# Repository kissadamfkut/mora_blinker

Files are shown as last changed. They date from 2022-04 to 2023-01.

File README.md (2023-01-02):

Mora-blinker
========== 
## Goals
  
- Provide a simple and cheap educational embedded project
- Demonstrate basic electric design 
- Demonstrate both C++ basics and advanced tricks
- More entertaining first program than a 'Hello world'
- Educate for software design in low-end environments

## How to use

- The schematics and the PCB board can be found in the hw folder. You can open the files with KiCAD 6
- The software is in the sw folder. Do not forget to also pull the git submodules!
- The build environment for the software includes avr-gcc 11.2, avrdude 6.4 and make 4.3
- Do not connect the battery when using a 5V ISP!
- After building the PCB, connect an STK500 or similar, and type ```make program```
- You can switch animations with the reset button

## Bill of materials

- CR2032 holder
- CR2032
- 100 nF capacitor
- Yellow LEDs (x5)
- 120 ohm resistors (x5)
- 9.1 kohm resistor
- Button
- ATtiny13A

## Theory of operation

The timer overflow interrupt drives a soft-PWM routine. The running animation changes an array of the LEDs' duty cycles. Resetting the device, the content of the SRAM is not random, so the index of the last animation is known, except for the cold-start, when it is random (not a problem). Some data is stored in the EEPROM to save space.
   
## Known issues  
  
- Fuse calculation could be more describing
- May further optimize base code
- Less numeric constant

## Work of a student

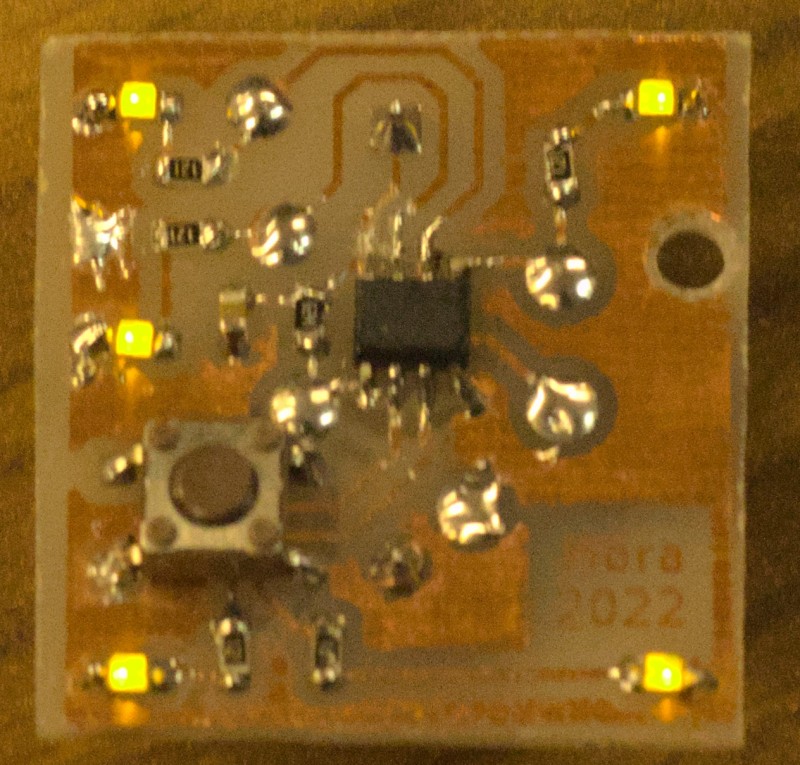
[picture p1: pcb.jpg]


## Full installion on Debian systems
```bash
sudo apt intsall gcc-avr avr-libc make avrdude
cd sw
make
make program
sudo apt install kdevelop #Optional
```

## Full installation on Windows systems (not tested)
- Install the lates AVR-GCC (for eg. https://blog.zakkemble.net/avr-gcc-builds/)
- Install Code::Blocks (https://www.codeblocks.org/)
- Open the project, and compile the elf file
- Use the driver of the programmer to deploy the code

## FAQ
Sometimes the programmers' device files are created with special permission on linux based systems. You should gather unix group membership to the proper group (dialout, uucp etc.), so you can program your device without sudo

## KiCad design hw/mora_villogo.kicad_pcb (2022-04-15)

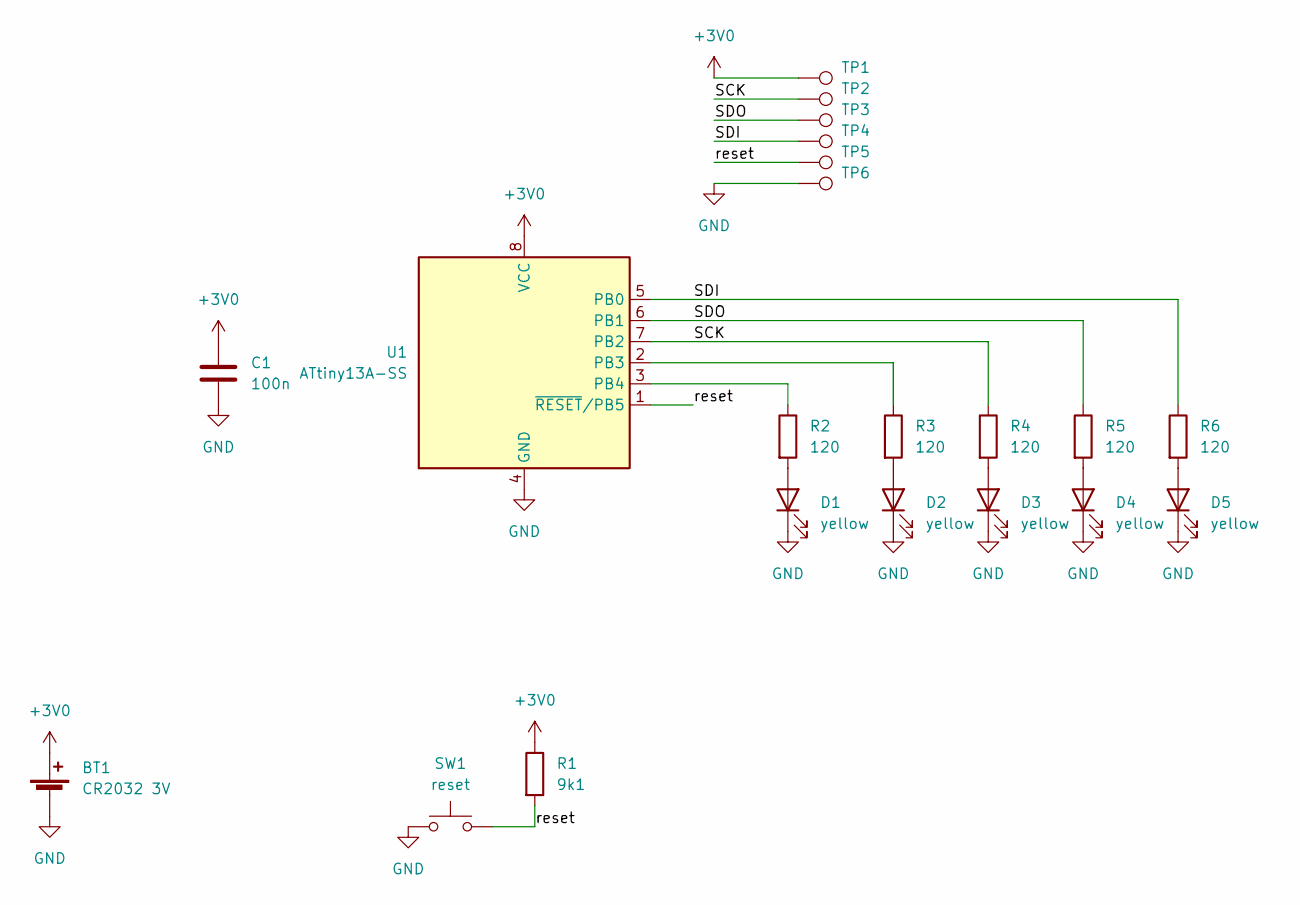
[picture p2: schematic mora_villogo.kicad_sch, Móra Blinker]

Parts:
BT1: CR2032 3V; BatteryHolder_ComfortableElectronic_CH273-2450_1x2450
C1: 100n; C_0805_2012Metric_Pad1.18x1.45mm_HandSolder
D1, D2, D3, D4, D5: yellow; LED_0805_2012Metric_Pad1.15x1.40mm_HandSolder
R1: 9k1; R_0805_2012Metric_Pad1.20x1.40mm_HandSolder
R2, R3, R4, R5, R6: 120; R_0805_2012Metric_Pad1.20x1.40mm_HandSolder
SW1: reset; SW_Push_1P1T_NO_6x6mm_H9.5mm
TP1, TP2, TP3, TP4, TP5, TP6: TestPoint; TestPoint_Pad_D3.0mm
U1: ATtiny13A-SS; SOIC-8_3.9x4.9mm_P1.27mm

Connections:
+3V0: BT1.1 (+), C1.1, R1.1, TP1.1, U1.8 (VCC)
/SCK: R4.1, TP2.1, U1.7 (PB2)
/SDI: R6.1, TP4.1, U1.5 (PB0)
/SDO: R5.1, TP3.1, U1.6 (PB1)
/reset: R1.2, SW1.2, TP5.1, U1.1 (~RESET/PB5)
GND: BT1.2 (-), C1.2, D1.1 (K), D2.1 (K), D3.1 (K), D4.1 (K), D5.1 (K), SW1.1, TP6.1, U1.4 (GND)
unnamed: D1.2 (A), R2.2
unnamed: D2.2 (A), R3.2
unnamed: D3.2 (A), R4.2
unnamed: D4.2 (A), R5.2
unnamed: D5.2 (A), R6.2
unnamed: R2.1, U1.3 (PB4)
unnamed: R3.1, U1.2 (PB3)

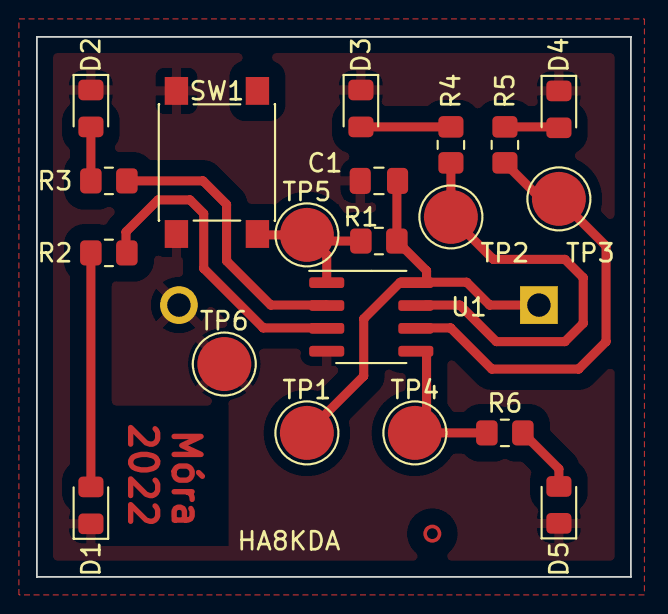
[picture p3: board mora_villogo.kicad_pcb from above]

Board: 2 copper layers, 33.0 x 30.0 mm, 21 parts (1 on the bottom side), 13 nets.

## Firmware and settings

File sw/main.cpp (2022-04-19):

#include <avr/io.h>
#include "leds.hpp"
#include <avr/interrupt.h>
#include "timing.hpp"

#include "onoff.hpp"
#include "powerdown.hpp"
#include "fade.hpp"
#include "rotate.hpp"

#include <array>
#include <eeprom_var.hpp>

namespace{ //student definied animations
#include "alma.hpp"
//#include "balint.hpp"
#include "bence.hpp"
#include "dominik.hpp"
#include "korte.hpp"
}

std::array<volatile uint8_t, number_of_leds> leds = {0};

[[noreturn]] static inline void program(){
	static const avr::eeprom_array anim [[gnu::section(".eeprom")]] = {fade, onoff<500>, rotate<1000>, powerdown, alma, bence, powerdown,/*balint, */ dominik<100>, korte, powerdown};

	static uint8_t anim_index [[gnu::section(".noinit")]];
	anim_index = (anim.size()-1) <= anim_index ? 0 : anim_index+1;

	const decltype(anim)::value_type act_anim = anim[anim_index];
label:
	act_anim();
	goto label;
}

static inline void hwinit(){
	TCCR0B=(1<<CS00);
	TIMSK0=(1<<TOIE0);
	DDRB=0b00011111; //PB0 -- PB4
	sei();
}

int main (){
	hwinit();
	delay_ms(100); //Debouncing the reset button
	program();
}

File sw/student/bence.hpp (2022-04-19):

#include"timing.hpp"
#include"leds.hpp"

void bence(){
	uint8_t light;

	leds[BOTTOM_LEFT]=4; // bal átló kezdete
	delay_ms(500);
	leds[BOTTOM_LEFT]=0;
	leds[TOP_RIGHT]=4;
	delay_ms(500);
	leds[TOP_RIGHT]=0;
	delay_ms(250);
	leds[BOTTOM_LEFT]=8;
	leds[TOP_RIGHT]=8;
	delay_ms(500);
	leds[BOTTOM_LEFT]=0;
	leds[TOP_RIGHT]=0;
	delay_ms(250); // bal átló vége
	leds[BOTTOM_RIGHT]=4; // jobb átló kezdete
	delay_ms(500);
	leds[BOTTOM_RIGHT]=0;
	leds[TOP_LEFT]=4;
	delay_ms(250);
	leds[BOTTOM_RIGHT]=8;
	leds[TOP_LEFT]=8;
	delay_ms(500);
	leds[BOTTOM_RIGHT]=0;
	leds[TOP_LEFT]=0;
	delay_ms(250); // jobb átló vége
	leds[TOP_MIDDLE]=4; // TOP middle solo
	delay_ms(500);
	leds[TOP_MIDDLE]=0;
	delay_ms(250);
	leds[TOP_MIDDLE]=8;
	delay_ms(500);
	leds[TOP_MIDDLE]=0;
	delay_ms(250); // és most mindenki
	leds[TOP_LEFT]=4;
	leds[TOP_MIDDLE]=4;
	leds[TOP_RIGHT]=4;
	leds[BOTTOM_LEFT]=4;
	leds[BOTTOM_RIGHT]=4;
	delay_ms(500);
	leds[TOP_LEFT]=0;
	leds[TOP_MIDDLE]=8;
	leds[TOP_RIGHT]=0;
	leds[BOTTOM_LEFT]=0;
	leds[BOTTOM_RIGHT]=0;
	delay_ms(250);
	leds[TOP_MIDDLE]=0;
	delay_ms(250);
	leds[TOP_LEFT]=8;
	leds[TOP_MIDDLE]=8;
	leds[TOP_RIGHT]=8;
	leds[BOTTOM_LEFT]=8;
	leds[BOTTOM_RIGHT]=8;
	delay_ms(500);
	leds[TOP_LEFT]=0;
	leds[TOP_MIDDLE]=0;
	leds[TOP_RIGHT]=0;
	leds[BOTTOM_LEFT]=0;
	leds[BOTTOM_RIGHT]=0;
	delay_ms(250);
	leds[TOP_LEFT]=16;
	leds[TOP_MIDDLE]=16;
	leds[TOP_RIGHT]=16;
	leds[BOTTOM_LEFT]=16;
	leds[BOTTOM_RIGHT]=16;




	for(light = 0; light<max_light;light++){
		leds[BOTTOM_LEFT]=light;
		leds[BOTTOM_RIGHT]=light;
		delay_ms(100);
	}

	delay_ms(300);

	for(light = 0; light<max_light;light++){
		leds[BOTTOM_LEFT]=max_light-light;
		leds[BOTTOM_RIGHT]=max_light-light;
		leds[TOP_LEFT]=light;
		leds[TOP_RIGHT]=light;
		delay_ms(100);
	}

	leds[TOP_MIDDLE]=max_light;

	while(true);
}

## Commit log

2022-04-15 Add HW
    [mora_villogo.kicad_pcb, mora_villogo.kicad_sch]
2022-04-18 Fix register saving in the interrupt of timing.cpp
    [timing.cpp]
